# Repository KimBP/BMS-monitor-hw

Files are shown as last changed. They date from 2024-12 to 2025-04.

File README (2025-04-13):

This repository contains a Kicad project defining the HW for the
bms-monitor project.

Version v2.0 is a prototype made for an esp32s3_devkitc with 9 or 10  modules 
between the two pin rows.

The display to use is a 3.5" TFT LCD shield based on a ILI9488 controller
with SPI.
Furthermore the display has an xpt2046 touch controller. Also SPI

TO CHANGE in next version:

- Diodes to make power possible both via NMEA connector and a separate power
  supply at the same time

- Buffer on 5V to 3V pins (CAN buffer to ESP32)

- Pullup on touch MISO

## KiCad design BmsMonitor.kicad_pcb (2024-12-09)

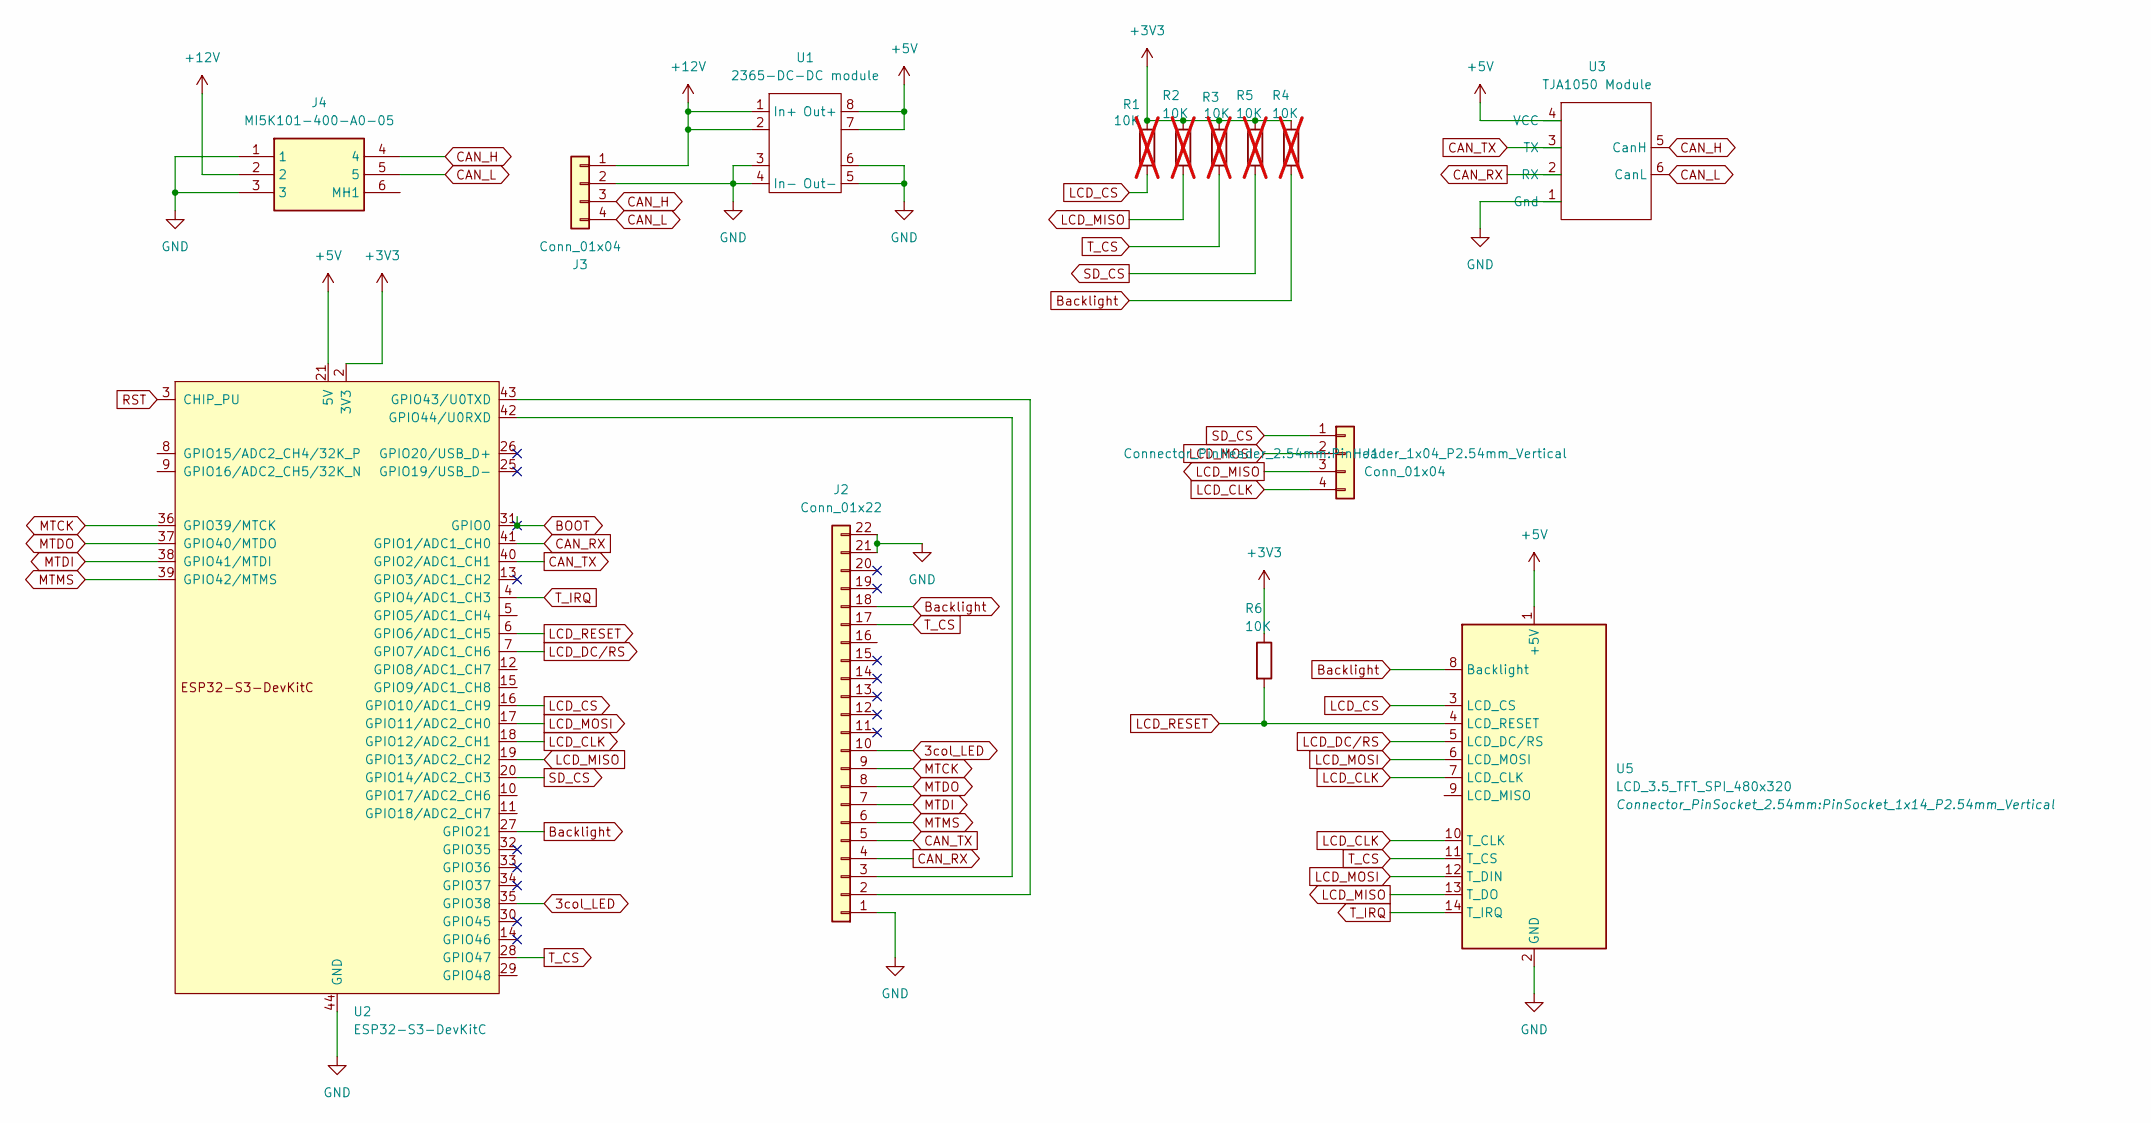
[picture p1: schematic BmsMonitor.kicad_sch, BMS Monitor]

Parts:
J1: Conn_01x04; PinHeader_1x04_P2.54mm_Vertical
J2: Conn_01x22; PinHeader_1x22_P2.54mm_Vertical
J3: Conn_01x04; TerminalBlock_bornier-4_P5.08mm
J4: MI5K101-400-A0-05; MI5K101400A005; Manufacturer_Part_Number MI5K101-400-A0-05
R1, R2, R3, R4, R5: 10K; R_Box_L8.4mm_W2.5mm_P5.08mm; not fitted
R6: 10K; R_Box_L8.4mm_W2.5mm_P5.08mm
U1: 2365-DC-DC module; DC-DC-2365-Module
U2: ESP32-S3-DevKitC
U3: TJA1050 Module; CAN_Transceiver_Module
U5: LCD_3.5_TFT_SPI_480x320; PinSocket_1x14_P2.54mm_Vertical

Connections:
3col_LED: J2.10, U2.35 (GPIO38)
+3V3: R1.1, R2.1, R3.1, R4.1, R5.1, R6.1, U2.1 (3V3), U2.2 (3V3)
+5V: U1.7, U1.8 (Out+), U2.21 (5V), U3.4 (VCC), U5.1 (+5V)
+12V: J3.1, J4.2, U1.1 (In+), U1.2
BOOT: U2.31 (GPIO0)
Backlight: J2.18, R4.2, U2.27 (GPIO21), U5.8 (Backlight)
CAN_H: J3.3, J4.4, U3.5 (CanH)
CAN_L: J3.4, J4.5, U3.6 (CanL)
CAN_RX: J2.4, U2.41 (GPIO1/ADC1_CH0), U3.2 (RX)
CAN_TX: J2.5, U2.40 (GPIO2/ADC1_CH1), U3.3 (TX)
GND: J2.1, J2.21, J2.22, J3.2, J4.1, J4.3, U1.3, U1.4 (In-), U1.5 (Out-), U1.6, U2.22 (GND), U2.23 (GND), U2.24 (GND), U2.44 (GND), U3.1 (Gnd), U5.2 (GND)
LCD_CLK: J1.4, U2.18 (GPIO12/ADC2_CH1), U5.7 (LCD_CLK), U5.10 (T_CLK)
LCD_CS: R1.2, U2.16 (GPIO10/ADC1_CH9), U5.3 (LCD_CS)
LCD_DC/RS: U2.7 (GPIO7/ADC1_CH6), U5.5 (LCD_DC/RS)
LCD_MISO: J1.3, R2.2, U2.19 (GPIO13/ADC2_CH2), U5.13 (T_DO)
LCD_MOSI: J1.2, U2.17 (GPIO11/ADC2_CH0), U5.6 (LCD_MOSI), U5.12 (T_DIN)
LCD_RESET: R6.2, U2.6 (GPIO6/ADC1_CH5), U5.4 (LCD_RESET)
MTCK: J2.9, U2.36 (GPIO39/MTCK)
MTDI: J2.7, U2.38 (GPIO41/MTDI)
MTDO: J2.8, U2.37 (GPIO40/MTDO)
MTMS: J2.6, U2.39 (GPIO42/MTMS)
unnamed: J2.2, U2.43 (GPIO43/U0TXD)
unnamed: J2.3, U2.42 (GPIO44/U0RXD)
RST: U2.3 (CHIP_PU)
SD_CS: J1.1, R5.2, U2.20 (GPIO14/ADC2_CH3)
T_CS: J2.17, R3.2, U2.28 (GPIO47), U5.11 (T_CS)
T_IRQ: U2.4 (GPIO4/ADC1_CH3), U5.14 (T_IRQ)

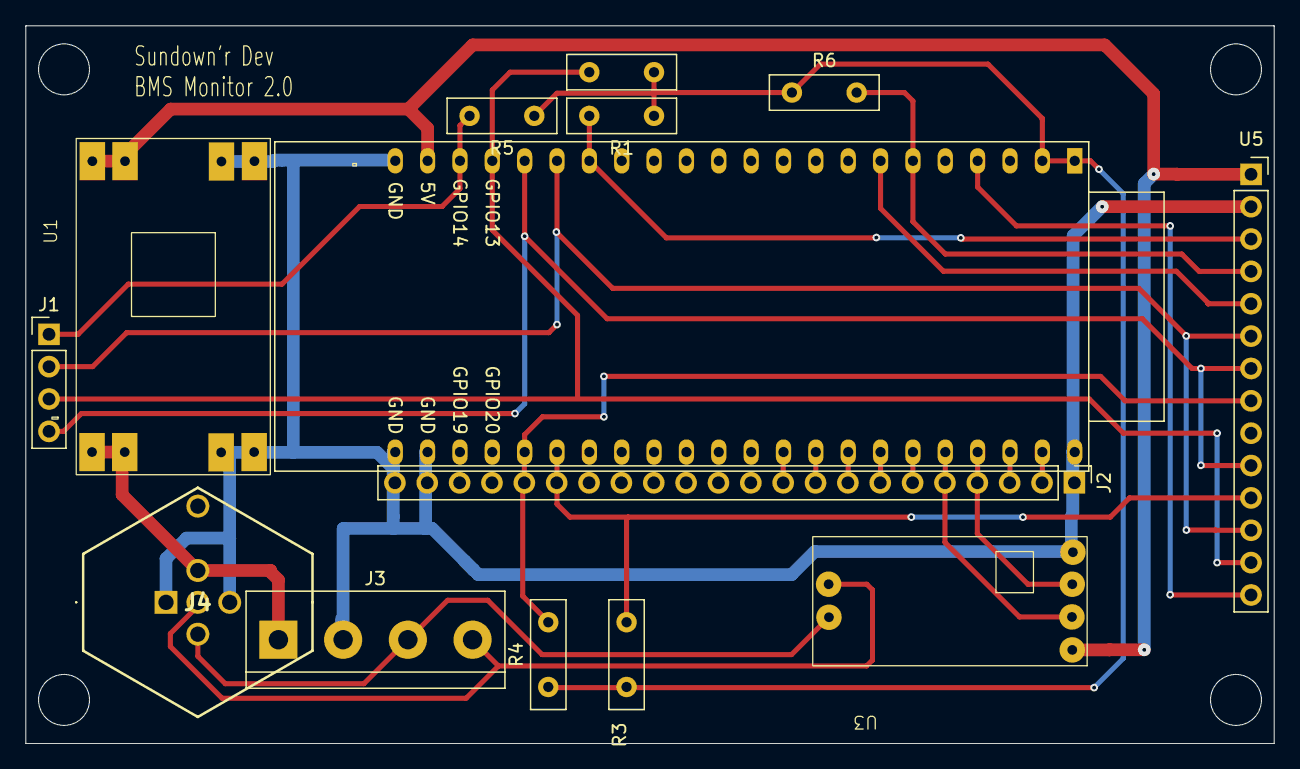
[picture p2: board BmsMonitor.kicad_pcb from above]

Board: 2 copper layers, 98.0 x 56.3 mm, 14 parts (0 on the bottom side), 25 nets.

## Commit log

2024-04-24 First version - using modules
    [BmsMonitor.kicad_pcb, BmsMonitor.kicad_sch]
2024-04-24 Gerber for version 1.0
    [BmsMonitor-B_Cu.gbr, BmsMonitor-B_Mask.gbr, BmsMonitor-B_Paste.gbr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]
2024-10-19 BmsMonitor Ver 2.0
    Changed to work with Display having a SPI variant of ILI9488
    as well as a XPT2046 touch controller.
    The display in question is this 3.5" display:
    https://www.aliexpress.com/item/33057812377.html
    [BmsMonitor.kicad_pcb, BmsMonitor.kicad_sch]
2024-10-19 Production files for V2.0 of the BMS Monitor
    [BmsMonitor-B_Cu.gbr, BmsMonitor-B_Mask.gbr, BmsMonitor-B_Paste.gbr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]
2024-12-09 Use common SPI for both display and touch.
    Added M12 connector for possible power and CAN
    [BmsMonitor.kicad_pcb, BmsMonitor.kicad_sch]
2024-12-09 Production files for V2.0 (second version) of the BMS monitor
    [BmsMonitor-B_Cu.gbr, BmsMonitor-B_Mask.gbr, BmsMonitor-B_Paste.gbr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]
